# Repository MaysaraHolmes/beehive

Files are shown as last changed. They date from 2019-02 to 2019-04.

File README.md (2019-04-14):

<p align="center">
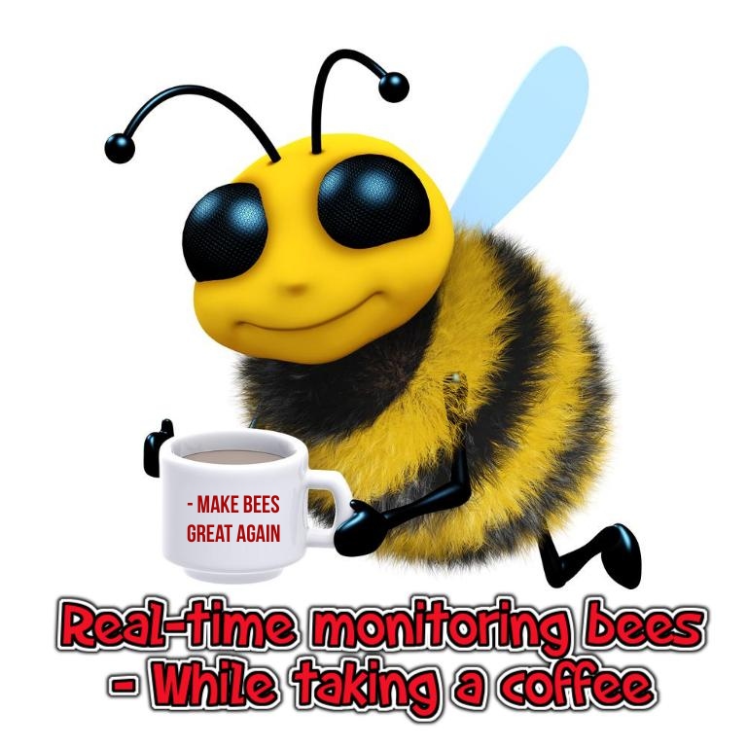
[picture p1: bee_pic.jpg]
FVCproductions Bee
</p>

# Real-Time Beehive Monitoring

We want to help beekeepers to keep an eye on their bees. By giving them insight on critical measurements we can monitor different events such as too low temperature, too high moisture, sufficient weight to harvest honey, as well as giving an estimate of how many bees went out of the beehive harvesting.

This project aims to set up a weather station with sensors and a fan to control the atmosphere inside the hive. The sensors output can be visualized through a website that can be hosted either locally on the Raspberry Pi, or hosted on the cloud (example [here](https://beehiveproject.herokuapp.com/)).

This project is done in partnership with the [Glasgow University Beekeeping Society](https://www.facebook.com/GUBeekeepingSociety/)

It was a success ! The Pi was able to make measurement of the ambiant temperature, pressure and humidity, as well as start the fan when the humidity got too high.

The website was displaying the value every 2 seconds while the fan was starting in as soon as the sensors triggered the alarm through a processor interrupt. Note, however, that the sensor provide data at more than 50Hz but it was decided the cap it to 2 second to avoid high traffic on the server (if hosted on the cloud).

## Table of contents
* [Setup](#setup)
* [General info](#general-info)
* [Technologies](#technologies)
* [Authors](#authors)
* [Images](#images)
* [Social media](#social-media)
## Setup

Instructions for installation can be found on the [installation wiki](https://github.com/MaysaraHolmes/beehive/wiki/Installation).

## General info
The code is simplified divided into three. Client, server and Fan. <br />
* The client is inteerupt by a timer every x millisecond reading the sensor data and sending it via udp to the server. <br />
* The server publish the data to our [example webpage](https://beehiveproject.herokuapp.com/) and saves the data to a database.
Additionally the server will send an email to registrered email-addresses everytime the humidity inside the beehive is too high. <br />
The website can be hosted either on a locally run server on the Raspberry Pi or hosted on a cloud based server.<br />
* The Fan is run depending on only one input pin. This pin is connected to the alarm on the humidity sensor inside the fan and will toggle instantaneously if the humidity goes above 80% humidity and off if it goes under 75% humidity. If the alarm pin toggles, it triggers an thread which will start or stop the fan depending if the pin goes high or low respectively. <br />
By this architecture the fan will be triggered even if the main code or the i2c bus fails to read the sensors. Making the code responsive and reliable. On the other hand if the alarm pin is disconnected you will still get an email/display on the webpage that the humidity inside the beehive is too high.
<br />
<br />
This projects architecture diagram:

<p align="center">
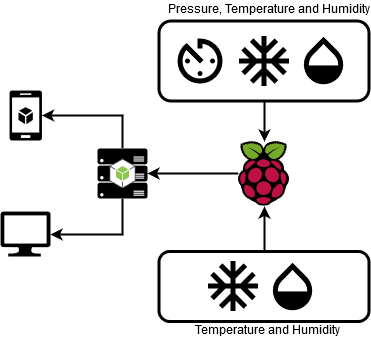
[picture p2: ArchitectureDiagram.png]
Architecture

</p>

Dependency graph for the C++ code:
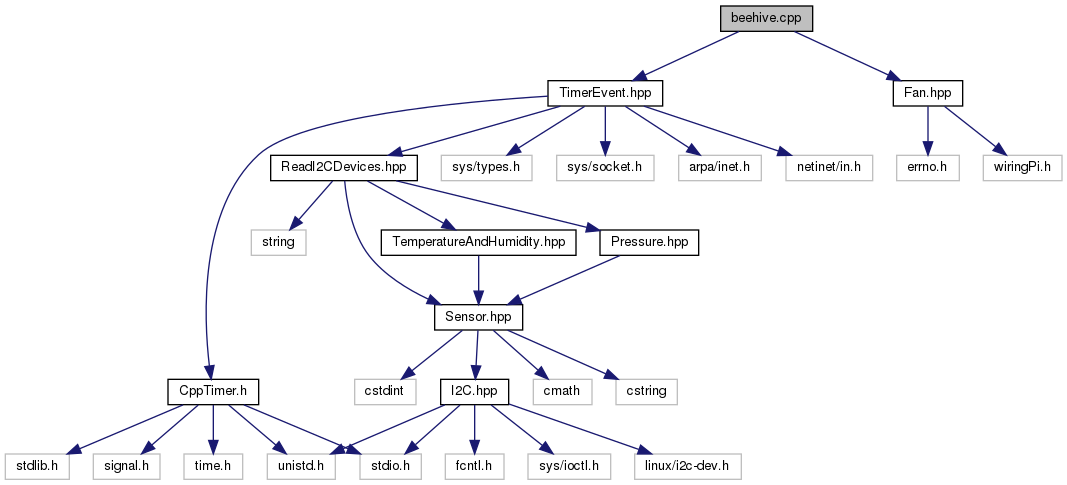
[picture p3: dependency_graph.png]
Dependency_graph

The doxygen generated c++ documentation can be found here: [beehive_code_documentation](https://github.com/MaysaraHolmes/beehive/blob/master/documentation/beehive_code_documentation.pdf)

## Technologies

Project is created with:
* Raspberry pi 3.0
* Sensors
	* ADC101C021 ADC
	* HIH6131 Temperatur & Humidity x2
	* MPL115A2 Barometer
	* P82B96 I2C Shifter
* Node Js/express Js server
* MySQL database.
* [WiringPi](http://wiringpi.com/reference/core-functions/) 
* [CppTimer.h](https://github.com/berndporr/cppTimer) 

## Authors

* **Remy Chatel, 2411062**  - [Github](https://github.com/RemyChatel) (Main responsibility: Hardware)

* **Maysara Alhindi, 2417665**  - [Github](https://github.com/MaysaraHolmes) (Main responsibility: Nodejs Server side and Front-end)

* **Trine Ødegård Olsen, 2420036**  - [Github](https://github.com/trineoo) (Main responsibility: C++ code)

## Images

The beehives in the backyard in the university of Glasgow
<p align="center">
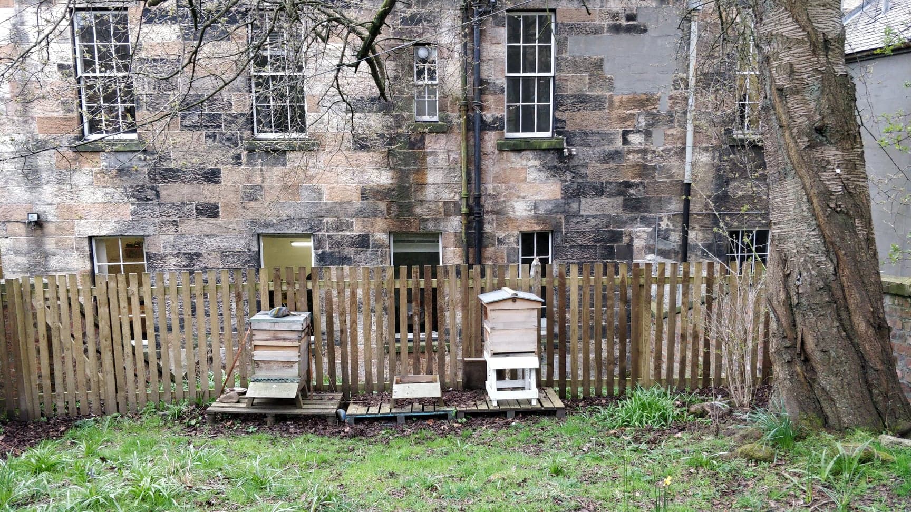
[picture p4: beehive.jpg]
beehive hive
	</p>
	 
Picture of the hardware, without the fan, soldered
<p align="center">
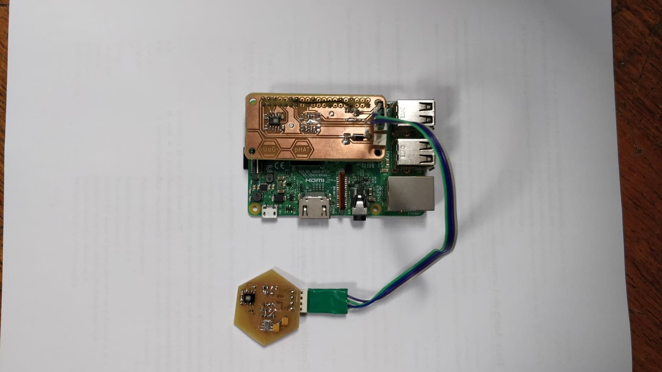
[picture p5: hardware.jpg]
hardware hw
	</p>

## Social media
* [Hackster](https://www.hackster.io/maysara-alhindi/real-time-beehive-monitoring-glasgow-university-5a986c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)
* [Hackaday](https://hackaday.io/project/164984-real-time-beehive-monitoring-glasgow-university)
* [Glasgow University Beekeeping Society](https://www.facebook.com/GUBeekeepingSociety/)

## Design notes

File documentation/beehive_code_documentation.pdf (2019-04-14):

## Beehive Project

### Generated by Doxygen 1.8.13

# Contents

1 Main Page | 1
2 Hierarchical Index | 3
3 Class Index | 5
4 File Index | 7
5 Class Documentation | 9

ii | CONTENTS

Generated by Doxygen

CONTENTS | iii

iv | CONTENTS
6 File Documentation | 37
Index | 39

## Chapter 1

# Main Page

Real-Time Beehive Monitoring

We want to help beekeepers to keep an eye on their bees. By giving them insight on critical measurements we can monitor different events such as too low temperature, too high moisture, sufficient weight to harvest honey, as well as giving an estimate of how many bees went out of the beehive harvesting.

Monitoring your beehive and get real-time measurements on the website (https://beehiveproject.herokuapp.com/)

This project is done in partnership with the Glasgow University Beekeeping Society (https://www.facebook.com/GUBeekeepingSociety/)

Table of contents

- Setup
- General info
- Technologies
- Authors

Setup

Instructions for installation can be found on the installation wiki. (https://github.com/MaysaraHolmes/beehive/wiki/Installation)

General info

This projects architecture diagram:

Dependency graph for the C++ code:

### 2 Main Page

Technologies

Project is created with:

- Raspberry pi 3.0
- Sensors

– ADC101C021 ADC
– HIH6131 Temperatur & Humidity x2 – MPL115A2 Barometer
– P82B96 I2C Shifter
- Node Js/express Js server
- MySQl database.

Authors

- Remy Chatel, 2411062 - Github (https://github.com/RemyChatel)
- Maysara Alhindi, 2417665 - Github (https://github.com/MaysaraHolmes)
- Trine Ødegård Olsen, 2420036 - Github (https://github.com/trineoo)

## Chapter 2

# Hierarchical Index

### 2.1 Class Hierarchy

This inheritance list is sorted roughly, but not completely, alphabetically:

CppTimer | 9
TimerEvent | 32
Fan | | 10
I2C | | 14
ReadI2CDevices | | 21
Sensor | | 25
Pressure | 16
TemperatureAndHumidity | 28

### 4 Hierarchical Index

## Chapter 3

# Class Index

### 3.1 Class List

Here are the classes, structs, unions and interfaces with brief descriptions:

Fan

I2C

Pressure

Sensor

TemperatureAndHumidity

### 6 Class Index

## Chapter 4

# File Index

### 4.1 File List

Here is a list of all documented files with brief descriptions:

CppTimer.h | ??
Fan.hpp | ??
I2C.hpp | ??
Pressure.hpp | | ??
ReadI2CDevices.hpp | | ??
Sensor.hpp | ??
TemperatureAndHumidity.hpp | ??
TimerEvent.hpp | ??

### 8 File Index

## Chapter 5

# Class Documentation

### 5.1 CppTimer Class Reference

Inheritance diagram for CppTimer:

CppTimer

TimerEvent

Public Member Functions

- void start (long nanosecs)
- virtual void timerEvent ()=0

Static Private Member Functions

- static void handler (int sig, siginfo_t ∗si, void ∗uc)

Private Attributes

- timer_t timerid
- struct sigevent sev
- struct sigaction sa
- struct itimerspec its

The documentation for this class was generated from the following file:

- CppTimer.h

### 10 Class Documentation

### 5.2 Fan Class Reference

A class to control Fan.

#include <Fan.hpp>

Collaboration diagram for Fan:

Fan saved_Fan_pointer

Public Member Functions

- Fan (int gpio=18, int interruptPin=22)

A constructor.
- void setPwm (int pwm_value)

Set the PWM value to the fan.
- void start ()

Start the Fan.
- void stop ()

Stop the Fan.
- ∼Fan ()

A destructor.

Static Public Member Functions

- static void onInterrupt ()

Static function triggers when the pin toggles.

Private Member Functions

- void setFanPointer ()

Set the static Fan pointer saved_Fan_pointer.

Private Attributes

- int gpio

A private variable.
- int interruptPin

A private variable.

5.2 Fan Class Reference | 11

Static Private Attributes

- static Fan ∗ saved_Fan_pointer = NULL

A private static variable.

### 5.2.1 Detailed Description

A class to control Fan.

Set different values for the Fan. Using a trigger pin connected to the humidity sensor inside the beehive, if the pin toggles (have threshold inside the sensor) it will trigger the onInterrupt() in this class and start or stop the Fan depending on if the pin goes to high or low.

### 5.2.2 Constructor & Destructor Documentation

### 5.2.2.1 Fan()

Fan::Fan (

int gpio = 18,

int interruptPin = 22 )

A constructor.

Set the private variables, default values is implemented

Parameters
gpio | an integer giving the gpio pin the fan is connected.
interruptPin | an integer giving the gpio pin the alarmpin is connected.

5.2.2.2 ∼Fan()

Fan::∼Fan ( )

A destructor.

Stops the Fan

### 5.2.3 Member Function Documentation

### 12 Class Documentation

### 5.2.3.1 onInterrupt()

void Fan::onInterrupt ( ) [static]

Static function triggers when the pin toggles.

Static to be called in real-time If the pin goes from high to low the stop() function is called If the pin goes from low to high the start() function is called

See also
start() and stop()

### 5.2.3.2 setFanPointer()

void Fan::setFanPointer ( ) [private]

Set the static Fan pointer saved_Fan_pointer.

Called by the constructor. Saves the objects in the corresponding private variables.

See also
Fan(int gpio = 18, int interruptPin=22), saved_Fan_pointer()

### 5.2.3.3 setPwm()

void Fan::setPwm (

int pwm_value )

Set the PWM value to the fan.

The PWM range is 0-1023.

### 5.2.3.4 start()

void Fan::start ( )

Start the Fan.

Calls the setPWM(1023) to maximise the Fan

See also
setPwm(int pwm_value)

5.2 Fan Class Reference | 13

### 5.2.3.5 stop()

void Fan::stop ( )

Stop the Fan.

Calls the setPWM(0) to stop the Fan

See also
setPwm(int pwm_value)

### 5.2.4 Member Data Documentation

### 5.2.4.1 gpio

int Fan::gpio [private]

A private variable.

Integer to hold the gpio pin the Fan is connected.

### 5.2.4.2 interruptPin

int Fan::interruptPin [private]

A private variable.

Integer to hold the gpio pin the alarmpin form humidity sensor is connected.

### 5.2.4.3 saved_Fan_pointer

Fan ∗ Fan::saved_Fan_pointer = NULL [static], [private]

A private static variable.

Assuming we only have one fan to trigger. Need a static pointer to the object so that the static interrupt function know which fan to set. If we have multiple fans on different pins, this has to be changed to a list/vector/pointer.

The documentation for this class was generated from the following files:

- Fan.hpp
- Fan.cpp

### 14 Class Documentation

### 5.3 I2C Class Reference

A I2C class handling the I2C bus.

#include <I2C.hpp>

Public Member Functions

- I2C (char ∗portI2C, int slaveAddr)

A constructor.
- void readI2C (int bytesToRead, unsigned char ∗global_buffer)

Read data from the peripheral .
- int writeI2C (int length, unsigned char ∗buffer)
- int writeI2C (int length)

Write data to the peripheral .

Private Attributes

- int file_i2c

A private variable.
- unsigned char buffer [5] = {0}

A private variable.

### 5.3.1 Detailed Description

A I2C class handling the I2C bus.

Handling I2C bus intended to allow multiple "slave" digital chips to communicate with the master i.e Raspberry PI. Every sensor connected to the bus has their own I2C-object.

### 5.3.2 Constructor & Destructor Documentation

### 5.3.2.1 I2C()

I2C::I2C (

char ∗ portI2C,

int slaveAddr )

A constructor.

Open the I2C bus and tell the kernel the I2C address of the slave.

Parameters
portI2C | a char pointer holding the which I2C bus on the Raspberry the peripheral is connected to.
slaveAddr | an integer holding the address to the peripheral.

5.3 I2C Class Reference | 15

### 5.3.3 Member Function Documentation

### 5.3.3.1 readI2C()

void I2C::readI2C (

int bytesToRead,

unsigned char ∗ global_buffer )

Read data from the peripheral .

Parameters
bytesToRead | an integer giving numbers of bytes to read.
global_buffer | an unsigned char pointer where the data read is saved.

### 5.3.3.2 writeI2C() [1/2]

int I2C::writeI2C (

int length,

unsigned char ∗ buffer )

Parameters
length | an integer giving numbers of bytes to write.
buffer | an unsigned char pointer pointing to the data to write.

### 5.3.3.3 writeI2C() [2/2]

int I2C::writeI2C (

int length )

Write data to the peripheral .

Using the private buffer in the object to write default value

Parameters
length an integer giving numbers of bytes to write.

### 16 Class Documentation

### 5.3.4 Member Data Documentation

### 5.3.4.1 buffer

unsigned char I2C::buffer[5] = {0} [private]

A private variable.

Used if you want to write to a peripheral, starting a conversation

### 5.3.4.2 file_i2c

int I2C::file_i2c [private]

A private variable.

To communicate with the I2C bus

The documentation for this class was generated from the following files:

- I2C.hpp
- I2C.cpp

### 5.4 Pressure Class Reference

A class for the MPL115A2 Barometer sensor.

#include <Pressure.hpp>

Inheritance diagram for Pressure:

Pressure

Sensor

5.4 Pressure Class Reference | 17

Collaboration diagram for Pressure:

Pressure

Sensor

I2C

bus

Public Member Functions
- Pressure (char ∗portI2C, int addrI2C, unsigned char ∗global_buffer)

A constructor.
- void readCoefficients (unsigned char ∗global_buffer)

Call the I2C-object write and read function to get sensor coefficients.
- void readI2C (unsigned char ∗global_buffer)

Call the I2C-object read function.
- int writeI2C ()

Call the I2C-object write function.
- float getPressure ()

Convert the humidity bits into kPa.
- float getTemp ()

Convert the temperature bits into degrees.
- ∼Pressure ()

A destructor.

Private Attributes
- float a0

A private variable.
- float b1

A private variable.
- float b2

A private variable.
- float c12

A private variable.
- int pressure

A private variable.
- int temp

A private variable.
- float pressureComp

A private variable.

### 18 Class Documentation

Additional Inherited Members

### 5.4.1 Detailed Description

A class for the MPL115A2 Barometer sensor.

Handling communication with the sensor, and converting the sensor measurements to human readable values

### 5.4.2 Constructor & Destructor Documentation

### 5.4.2.1 Pressure()

Pressure::Pressure (

char ∗ portI2C,

int addrI2C,

unsigned char ∗ global_buffer )

A constructor.

Call the Sensor constructor and readCoefficients(unsigned char∗ global_buffer)

Parameters
portI2C | a char pointer holding the which I2C bus on the Raspberry the peripheral is connected to.
addrI2C | an integer holding the address to the peripheral.

See also
Sensor(int bytesToRead, int bytesToWrite, char∗ portI2C, int addrI2C)

5.4.2.2 ∼Pressure()

Pressure::∼Pressure ( )

A destructor.

Empty, can be used if more functions are integrated

### 5.4.3 Member Function Documentation

5.4 Pressure Class Reference | 19

### 5.4.3.1 getPressure()

float Pressure::getPressure ( )

Convert the humidity bits into kPa.

Returns
The humidity in kPa.

### 5.4.3.2 getTemp()

float Pressure::getTemp ( )

Convert the temperature bits into degrees.

Returns
The temperature in degrees.

### 5.4.3.3 readCoefficients()

void Pressure::readCoefficients (

unsigned char ∗ global_buffer )

Call the I2C-object write and read function to get sensor coefficients.

Write (uint8_t)(0x04) to the sensor, followed by a read to get the coefficients we need to decrypt the values from the pressure sensor. Saves the coefficients in the corresponding private variables.

Parameters
global_buffer an unsigned char pointer where the data read is saved.

### 5.4.3.4 readI2C()

void Pressure::readI2C (

unsigned char ∗ global_buffer ) [virtual]
Call the I2C-object read function.

Get the data read form the sensor and split the data into pressure, temperature and calculate the pressure compo-nent bits and saves them to the corresponding private variable.

### 20 Class Documentation

Parameters
global_buffer an unsigned char pointer where the data read is saved.

Implements Sensor.

### 5.4.4 Member Data Documentation

### 5.4.4.1 a0

float Pressure::a0 [private]
A private variable.

variable to hold the floating point coefficient a0 needed to convert the read sensor bit to a human readable value

### 5.4.4.2 b1

float Pressure::b1 [private]
A private variable.

variable to hold the floating point coefficient b1 needed to convert the read sensor bit to a human readable value

### 5.4.4.3 b2

float Pressure::b2 [private]
A private variable.

variable to hold the floating point coefficient b2 needed to convert the read sensor bit to a human readable value

### 5.4.4.4 c12

float Pressure::c12 [private]
A private variable.

variable to hold the floating point coefficient c2 needed to convert the read sensor bit to a human readable value

### 5.4.4.5 pressure

int Pressure::pressure [private]
A private variable.

Holding the newest pressure-bit reading from the sensor

5.5 ReadI2CDevices Class Reference | 21

### 5.4.4.6 pressureComp

float Pressure::pressureComp [private]

A private variable.

Intermediate variable needed to convert the sensor data to a human readable value. Calculated by combining all the private variables

### 5.4.4.7 temp

int Pressure::temp [private]

A private variable.

Holding the newest temperature-bit reading from the sensor

The documentation for this class was generated from the following files:

- Pressure.hpp
- Pressure.cpp

### 5.5 ReadI2CDevices Class Reference

Collaboration diagram for ReadI2CDevices:

ReadI2CDevices

Sensor

pr
th1
th2

I2C

bus

### 22 Class Documentation

Public Member Functions

- ReadI2CDevices ()

A constructor.
- void writeAll ()

Write to all the peripherals.
- std::string readAll ()

Read data from all the peripherals.
- ∼ReadI2CDevices ()

A destructor.

Private Member Functions

- void createSensorObjects ()

Create all the sensor objects we want to communicate with.

Private Attributes

- unsigned char global_buffer [20] ={0}

A private variable.
- Sensor ∗ th1

A private variable.
- Sensor ∗ th2

A private variable.
- Sensor ∗ pr

A private variable.

### 5.5.1 Constructor & Destructor Documentation

### 5.5.1.1 ReadI2CDevices()

ReadI2CDevices::ReadI2CDevices ( )

A constructor.

Call the function createSensorObjects();

See also
createSensorObjects()

5.5 ReadI2CDevices Class Reference | 23

5.5.1.2 ∼ReadI2CDevices()

ReadI2CDevices::∼ReadI2CDevices ( )

A destructor.

Deallocates memory from heap

### 5.5.2 Member Function Documentation

### 5.5.2.1 createSensorObjects()

void ReadI2CDevices::createSensorObjects ( ) [private]

Create all the sensor objects we want to communicate with.

Called by the constructor. Saves the objects in the corresponding private variables.

See also
ReadI2CDevices();

### 5.5.2.2 readAll()

std::string ReadI2CDevices::readAll ( )

Read data from all the peripherals.

Call the pure virtual function readI2C(unsigned char∗ global_buffer) in Sensor.hpp for all the sensors. Sends the private global_buffer to save the readings.

Returns
A string of all the human readable data read form the sensors

See also
readI2C(unsigned char∗ global_buffer) = 0;

### 24 Class Documentation

### 5.5.2.3 writeAll()

void ReadI2CDevices::writeAll ( )
Write to all the peripherals.

Call the virtual function writeI2C() in Sensor.hpp for all the sensors

See also
writeI2C()

### 5.5.3 Member Data Documentation

### 5.5.3.1 global_buffer

unsigned char ReadI2CDevices::global_buffer[20] ={0} [private]
A private variable.

Global buffer where all the sensors saves the measurements.

### 5.5.3.2 pr

Sensor∗ ReadI2CDevices::pr [private]

A private variable.

Sensor object, pointing to the pressure sensor on I2C bus 1.

### 5.5.3.3 th1

Sensor∗ ReadI2CDevices::th1 [private]

A private variable.

Sensor object, pointing to the temperature and humidity sensor on I2C bus 1.

### 5.5.3.4 th2

Sensor∗ ReadI2CDevices::th2 [private]

A private variable.

Sensor object, pointing to the temperature and humidity sensor on I2C bus 2.

The documentation for this class was generated from the following files:

- ReadI2CDevices.hpp
- ReadI2CDevices.cpp

5.6 Sensor Class Reference | 25

### 5.6 Sensor Class Reference

An abstract class.

#include <Sensor.hpp>

Inheritance diagram for Sensor:

Sensor

Pressure TemperatureAndHumidity

Collaboration diagram for Sensor:

Sensor

I2C

bus

Public Member Functions

- Sensor (int bytesToRead, int bytesToWrite, char ∗portI2C, int addrI2C)

A constructor.
- virtual void readI2C (unsigned char ∗global_buffer)=0

A pure virtual member.
- virtual int writeI2C ()

A virtual member.
- ∼Sensor ()

A destructor.

### 26 Class Documentation

Protected Attributes

- int bytesToRead

A private variable.
- int bytesToWrite

A private variable.
- I2C ∗ bus

A private variable.

### 5.6.1 Detailed Description

An abstract class.

Used as a base class for sensors connected to the I2C bus of the RaspberryPi

### 5.6.2 Constructor & Destructor Documentation

### 5.6.2.1 Sensor()

Sensor::Sensor (

int bytesToRead,

int bytesToWrite,

char ∗ portI2C,

int addrI2C ) [inline]

A constructor.

Create a new I2C object used to communicate with the sensor.

Parameters
bytesToRead | default bytes to read form the I2C bus
bytesToWrite | default bytes to write form the I2C bus
portI2C | a char pointer holding which I2C bus on the Raspberry the peripheral is connected to.
addrI2C | an integer holding the address to the peripheral.

See also
I2C(char∗ portI2C, int slaveAddr)

5.6.2.2 ∼Sensor()

Sensor::∼Sensor ( ) [inline]
A destructor.
Deallocates memory from heap

5.6 Sensor Class Reference | 27

### 5.6.3 Member Function Documentation

### 5.6.3.1 readI2C()

virtual void Sensor::readI2C (

unsigned char ∗ global_buffer ) [pure virtual]

A pure virtual member.

Read data from the peripheral .

Parameters
global_buffer an unsigned char pointer where the data read is saved.

Implemented in Pressure, and TemperatureAndHumidity.

### 5.6.3.2 writeI2C()

virtual int Sensor::writeI2C ( ) [inline], [virtual]
A virtual member.

Write data to the peripheral .

Reimplemented in Pressure, and TemperatureAndHumidity.

### 5.6.4 Member Data Documentation

### 5.6.4.1 bus

I2C∗ Sensor::bus [protected]

A private variable.

Holding the sensor I2C bus object created in the constructor

### 5.6.4.2 bytesToRead

int Sensor::bytesToRead [protected]
A private variable.

Holding the sensor default bytes to read form the I2C bus

### 28 Class Documentation

### 5.6.4.3 bytesToWrite

int Sensor::bytesToWrite [protected]
A private variable.

Holding the sensor default bytes to write form the I2C bus

The documentation for this class was generated from the following file:

- Sensor.hpp

### 5.7 TemperatureAndHumidity Class Reference

A class for the HIH6131 Temperatur & Humidity sensor.

#include <TemperatureAndHumidity.hpp>

Inheritance diagram for TemperatureAndHumidity:

TemperatureAndHumidity

Sensor

Collaboration diagram for TemperatureAndHumidity:

TemperatureAndHumidity

Sensor

I2C

bus

5.7 TemperatureAndHumidity Class Reference | 29

Public Member Functions

- TemperatureAndHumidity (char ∗portI2C, int addrI2C)

A constructor.
- void readI2C (unsigned char ∗global_buffer)

Call the I2C-object read function.
- int writeI2C ()

Call the I2C-object write function.
- unsigned int getStatus ()

Convert the status bits into a integer from 0-3.
- double getTemp ()

Convert the temperature bits into degrees.
- double getHum ()

Convert the humidity bits into RH.
- ∼TemperatureAndHumidity ()

A destructor.

Private Attributes

- uint8_t status

A private variable.
- uint16_t humidity

A private variable.
- uint16_t temperature

A private variable.

Additional Inherited Members

### 5.7.1 Detailed Description

A class for the HIH6131 Temperatur & Humidity sensor.

Handling how to communicate with the sensor, and converting the sensor measurements to human readable values

### 5.7.2 Constructor & Destructor Documentation

### 5.7.2.1 TemperatureAndHumidity()

TemperatureAndHumidity::TemperatureAndHumidity (

char ∗ portI2C,

int addrI2C )

A constructor.

Call the Sensor constructor

### 30 Class Documentation

Parameters
portI2C | a char pointer holding the which I2C bus on the Raspberry the peripheral is connected to.
addrI2C | an integer holding the address to the peripheral.

See also
Sensor(int bytesToRead, int bytesToWrite, char∗ portI2C, int addrI2C)

5.7.2.2 ∼TemperatureAndHumidity()

TemperatureAndHumidity::∼TemperatureAndHumidity ( )

A destructor.

Empty, can be used if more functions are integrated

### 5.7.3 Member Function Documentation

### 5.7.3.1 getHum()

double TemperatureAndHumidity::getHum ( )

Convert the humidity bits into RH.

Returns
The humidity in RH.

### 5.7.3.2 getStatus()

unsigned int TemperatureAndHumidity::getStatus ( )

Convert the status bits into a integer from 0-3.

Returns
The status of the sensor.

5.7 TemperatureAndHumidity Class Reference | 31

### 5.7.3.3 getTemp()

double TemperatureAndHumidity::getTemp ( )

Convert the temperature bits into degrees.

Returns
The temperature in degrees.

### 5.7.3.4 readI2C()

void TemperatureAndHumidity::readI2C (

unsigned char ∗ global_buffer ) [virtual]

Call the I2C-object read function.

Get the data read form the sensor and split the data into status, humidity and temperatur bits and saves them to the corresponding private variable.

Parameters
global_buffer an unsigned char pointer where the data read is saved.

Implements Sensor.

### 5.7.4 Member Data Documentation

### 5.7.4.1 humidity

uint16_t TemperatureAndHumidity::humidity [private]

A private variable.

Holding the newest humidity-bit reading from the sensor

### 5.7.4.2 status

uint8_t TemperatureAndHumidity::status [private]

A private variable.

Holding the newest status-bit reading from the sensor

### 32 Class Documentation

### 5.7.4.3 temperature

uint16_t TemperatureAndHumidity::temperature [private]

A private variable.

Holding the newest temperature-bit reading from the sensor

The documentation for this class was generated from the following files:

- TemperatureAndHumidity.hpp
- TemperatureAndHumidity.cpp

### 5.8 TimerEvent Class Reference

Inheritance diagram for TimerEvent:

TimerEvent

CppTimer

5.8 TimerEvent Class Reference | 33

Collaboration diagram for TimerEvent:

Public Member Functions

- TimerEvent ()

A constructor.
- ∼TimerEvent ()

A destructor.

Private Member Functions

- void timerEvent ()

A private member.

Private Attributes

- ReadI2CDevices ∗ r

A private variable.
- int sockfd

A private variable.
- struct sockaddr_in servaddr

A private variable.

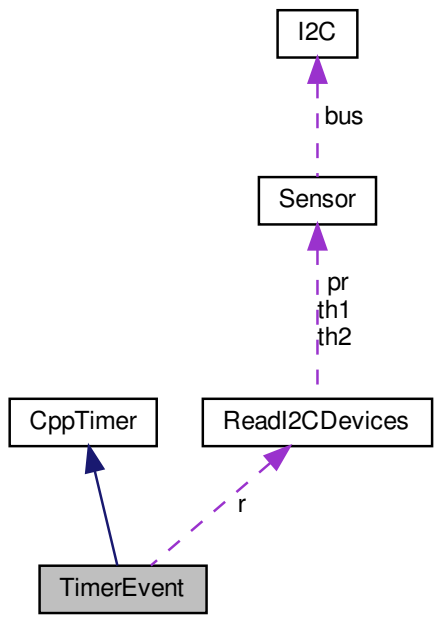
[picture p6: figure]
TimerEvent; CppTimer; ReadI2CDevices; Sensor; bus

### 34 Class Documentation

### 5.8.1 Constructor & Destructor Documentation

### 5.8.1.1 TimerEvent()

TimerEvent::TimerEvent ( )

A constructor.

Create a new ReadI2CDevices-object and saves it to the corresponding private variable. Setup and configure the socket

5.8.1.2 ∼TimerEvent()

TimerEvent::∼TimerEvent ( )

A destructor.

Deallocates memory from heap

### 5.8.2 Member Function Documentation

### 5.8.2.1 timerEvent()

void TimerEvent::timerEvent ( ) [private], [virtual]

A private member.

Called by the CppTimer.h Get a string of all the sensor data and send it to the server

Implements CppTimer.

### 5.8.3 Member Data Documentation

### 5.8.3.1 r

ReadI2CDevices∗ TimerEvent::r [private]

A private variable.

Object to get all the gathered sensor data.

5.8 TimerEvent Class Reference | 35

### 5.8.3.2 servaddr

struct sockaddr_in TimerEvent::servaddr [private]

A private variable.

Struct containing the server address, port number and host number

### 5.8.3.3 sockfd

int TimerEvent::sockfd [private]

A private variable.

The socket created in the constructor

The documentation for this class was generated from the following files:

- TimerEvent.hpp
- TimerEvent.cpp

### 36 Class Documentation

## Chapter 6

# File Documentation

### 6.1 beehive.cpp File Reference

#include "TimerEvent.hpp"

#include "Fan.hpp"

Include dependency graph for beehive.cpp:

beehive.cpp

TimerEvent.hpp | Fan.hpp

CppTimer.h

ReadI2CDevices.hpp | sys/types.h | sys/socket.h | arpa/inet.h | netinet/in.h
stdlib.h | signal.h | time.h | unistd.h | stdio.h

TemperatureAndHumidity.hpp

Sensor.hpp

string | Pressure.hpp
cstdint | I2C.hpp | cmath | cstring
fcntl.h | sys/ioctl.h | linux/i2c-dev.h
errno.h | wiringPi.h

Functions

- int main (int argc, const char ∗argv[ ])

### 6.1.1 Detailed Description

Project start

### 6.1.2 Function Documentation

### 38 File Documentation

### 6.1.2.1 main()

int main (

int argc,

const char ∗ argv[ ] )

Create a Fan object so the interrupt bin is set to the default value (using the default gpio pin in the Fan constructor) Create a TimerEvent object to start the timer which trigger the sensor-readings.

# Index

∼Fan
Fan, 11
∼Pressure
Pressure, 18
∼ReadI2CDevices
ReadI2CDevices, 22
∼Sensor
Sensor, 26
∼TemperatureAndHumidity
TemperatureAndHumidity, 30 ∼TimerEvent
TimerEvent, 34

a0
Pressure, 20

b1
Pressure, 20
b2
Pressure, 20
beehive.cpp, 37
main, 37
buffer
I2C, 16
bus
Sensor, 27
bytesToRead
Sensor, 27
bytesToWrite
Sensor, 27

c12
Pressure, 20
CppTimer, 9
createSensorObjects
ReadI2CDevices, 23

Fan, 10
∼Fan, 11
Fan, 11
gpio, 13
interruptPin, 13
onInterrupt, 11
saved_Fan_pointer, 13
setFanPointer, 12
setPwm, 12
start, 12
stop, 12
file_i2c
I2C, 16

getHum
TemperatureAndHumidity, 30 getPressure
Pressure, 18
getStatus
TemperatureAndHumidity, 30 getTemp
Pressure, 19
TemperatureAndHumidity, 30 global_buffer
ReadI2CDevices, 24
gpio
Fan, 13

humidity
TemperatureAndHumidity, 31

I2C, 14
buffer, 16
file_i2c, 16
I2C, 14
readI2C, 15
writeI2C, 15
interruptPin
Fan, 13

main
beehive.cpp, 37

onInterrupt
Fan, 11

pr
ReadI2CDevices, 24
Pressure, 16
∼Pressure, 18
a0, 20
b1, 20
b2, 20
c12, 20
getPressure, 18
getTemp, 19
Pressure, 18
pressure, 20
pressureComp, 20
readCoefficients, 19
readI2C, 19
temp, 21
pressure
Pressure, 20
pressureComp

### 40 INDEX

Pressure, 20

r
TimerEvent, 34
readAll
ReadI2CDevices, 23
readCoefficients
Pressure, 19
ReadI2CDevices, 21
∼ReadI2CDevices, 22
createSensorObjects, 23
global_buffer, 24
pr, 24
readAll, 23
ReadI2CDevices, 22
th1, 24
th2, 24
writeAll, 23
readI2C
I2C, 15
Pressure, 19
Sensor, 27
TemperatureAndHumidity, 31

saved_Fan_pointer
Fan, 13
Sensor, 25
∼Sensor, 26
bus, 27
bytesToRead, 27
bytesToWrite, 27
readI2C, 27
Sensor, 26
writeI2C, 27
servaddr
TimerEvent, 34
setFanPointer
Fan, 12
setPwm
Fan, 12
sockfd
TimerEvent, 35
start
Fan, 12
status
TemperatureAndHumidity, 31 stop
Fan, 12

temp
Pressure, 21
temperature
TemperatureAndHumidity, 31 TemperatureAndHumidity, 28 ∼TemperatureAndHumidity, 30 getHum, 30
getStatus, 30
getTemp, 30
humidity, 31

readI2C, 31
status, 31
temperature, 31
TemperatureAndHumidity, 29 th1
ReadI2CDevices, 24
th2
ReadI2CDevices, 24
TimerEvent, 32
∼TimerEvent, 34
r, 34
servaddr, 34
sockfd, 35
TimerEvent, 34
timerEvent, 34
timerEvent
TimerEvent, 34

writeAll
ReadI2CDevices, 23
writeI2C
I2C, 15
Sensor, 27

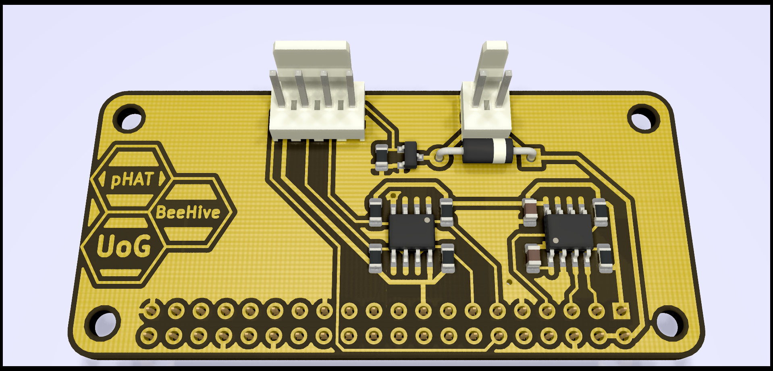
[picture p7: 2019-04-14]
documentation/pHAT_v3.3_barecopper.png

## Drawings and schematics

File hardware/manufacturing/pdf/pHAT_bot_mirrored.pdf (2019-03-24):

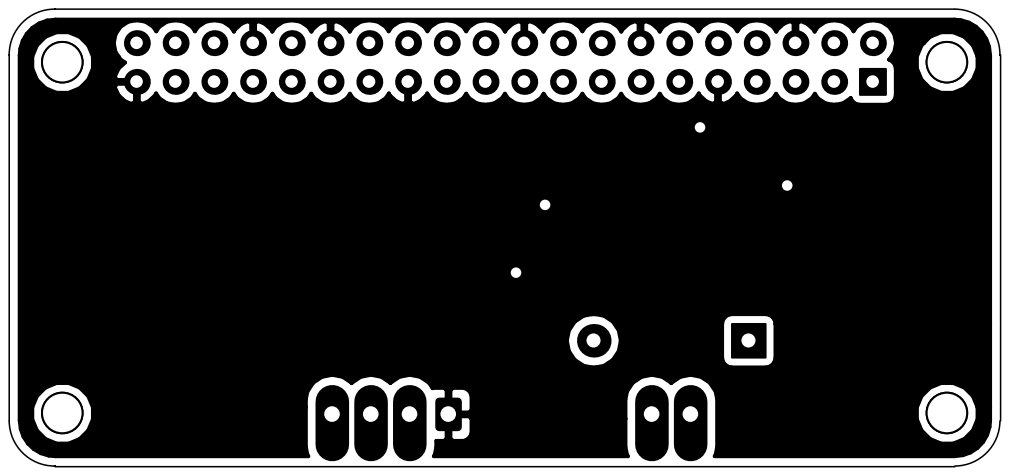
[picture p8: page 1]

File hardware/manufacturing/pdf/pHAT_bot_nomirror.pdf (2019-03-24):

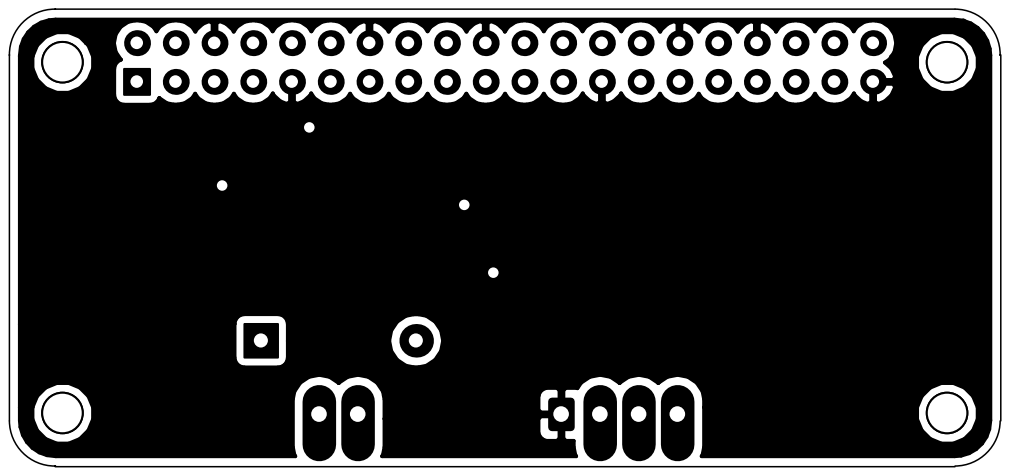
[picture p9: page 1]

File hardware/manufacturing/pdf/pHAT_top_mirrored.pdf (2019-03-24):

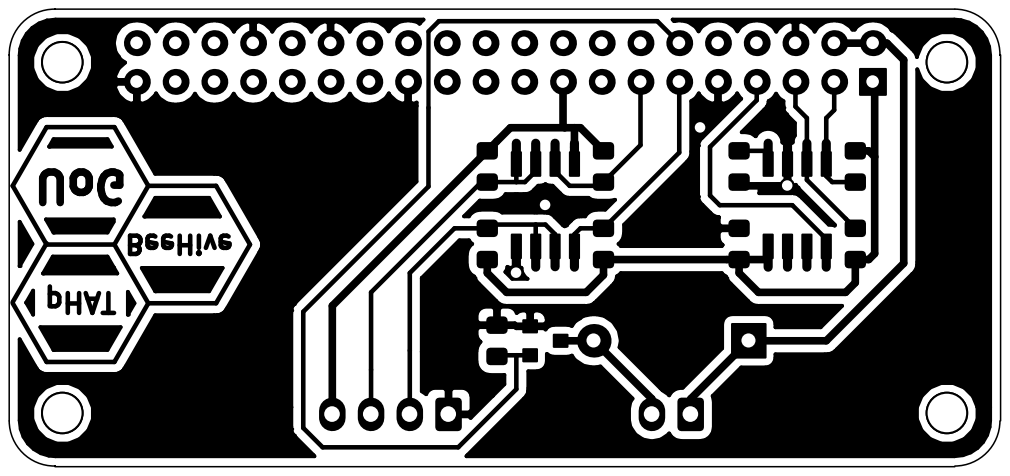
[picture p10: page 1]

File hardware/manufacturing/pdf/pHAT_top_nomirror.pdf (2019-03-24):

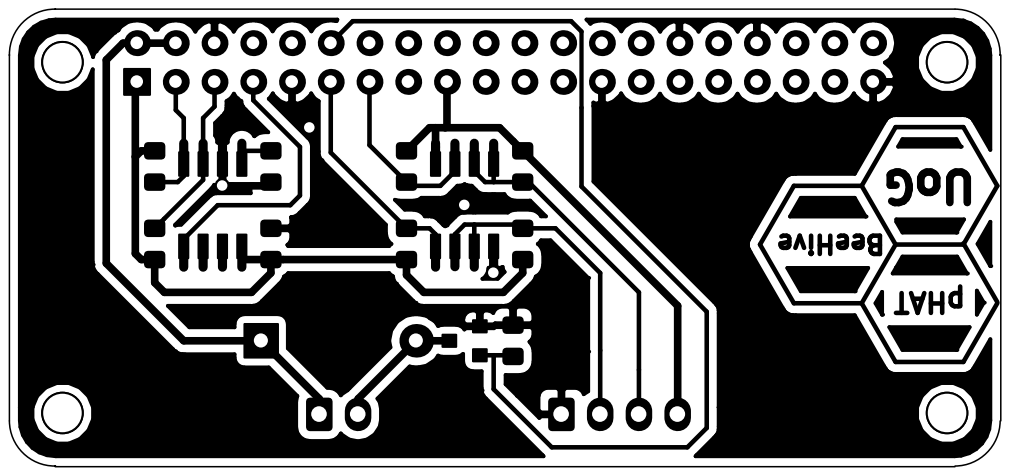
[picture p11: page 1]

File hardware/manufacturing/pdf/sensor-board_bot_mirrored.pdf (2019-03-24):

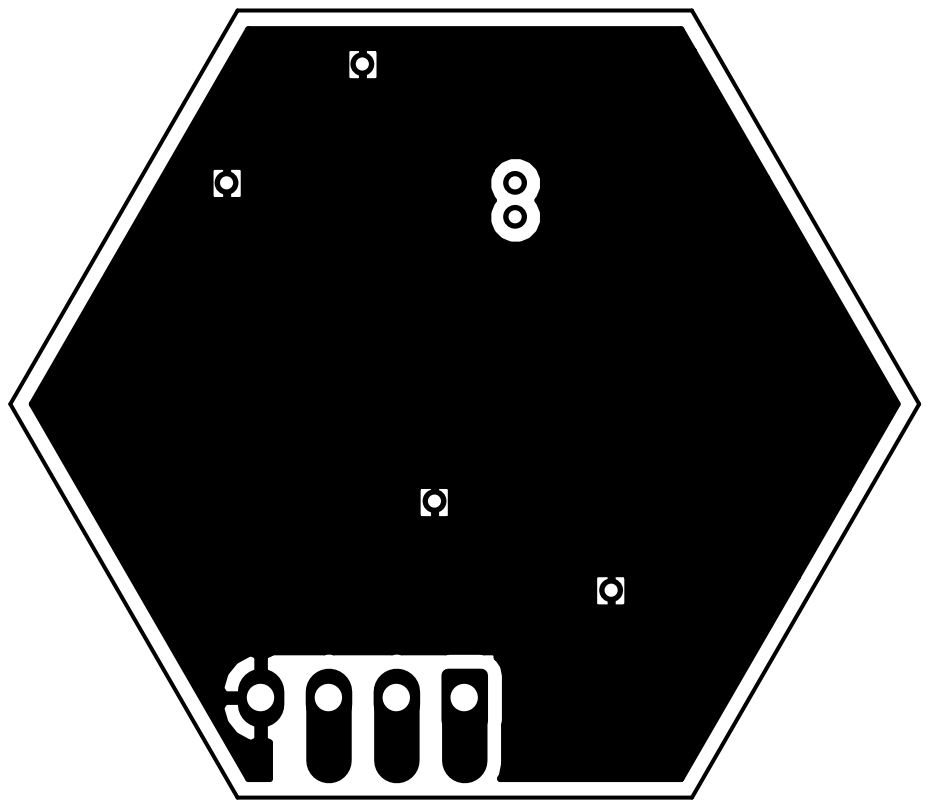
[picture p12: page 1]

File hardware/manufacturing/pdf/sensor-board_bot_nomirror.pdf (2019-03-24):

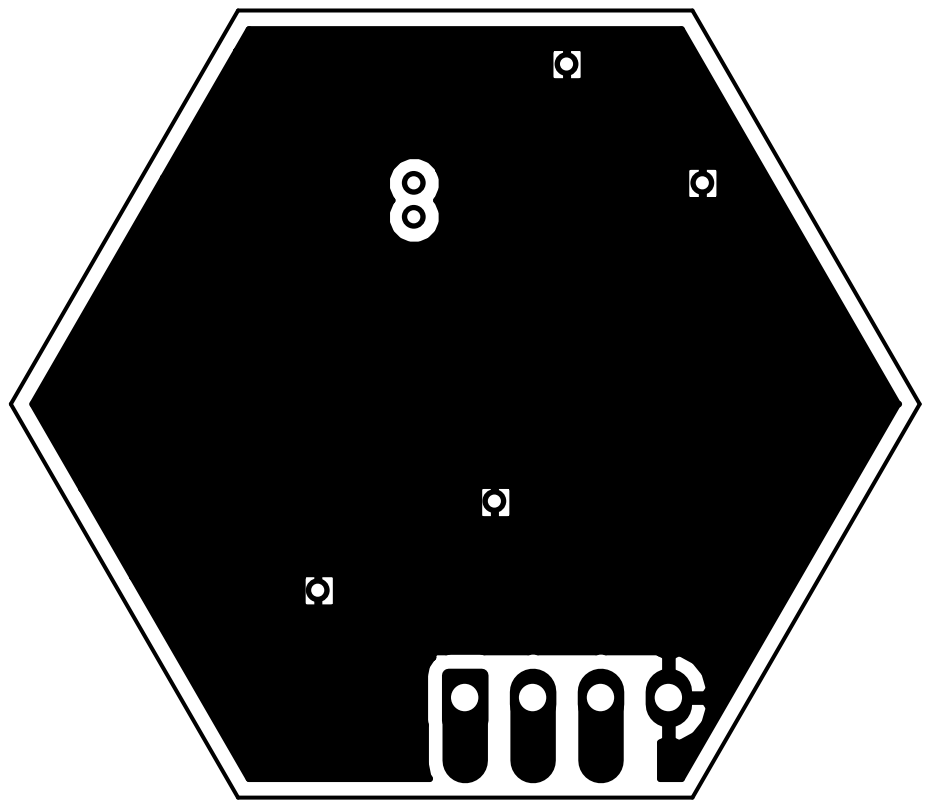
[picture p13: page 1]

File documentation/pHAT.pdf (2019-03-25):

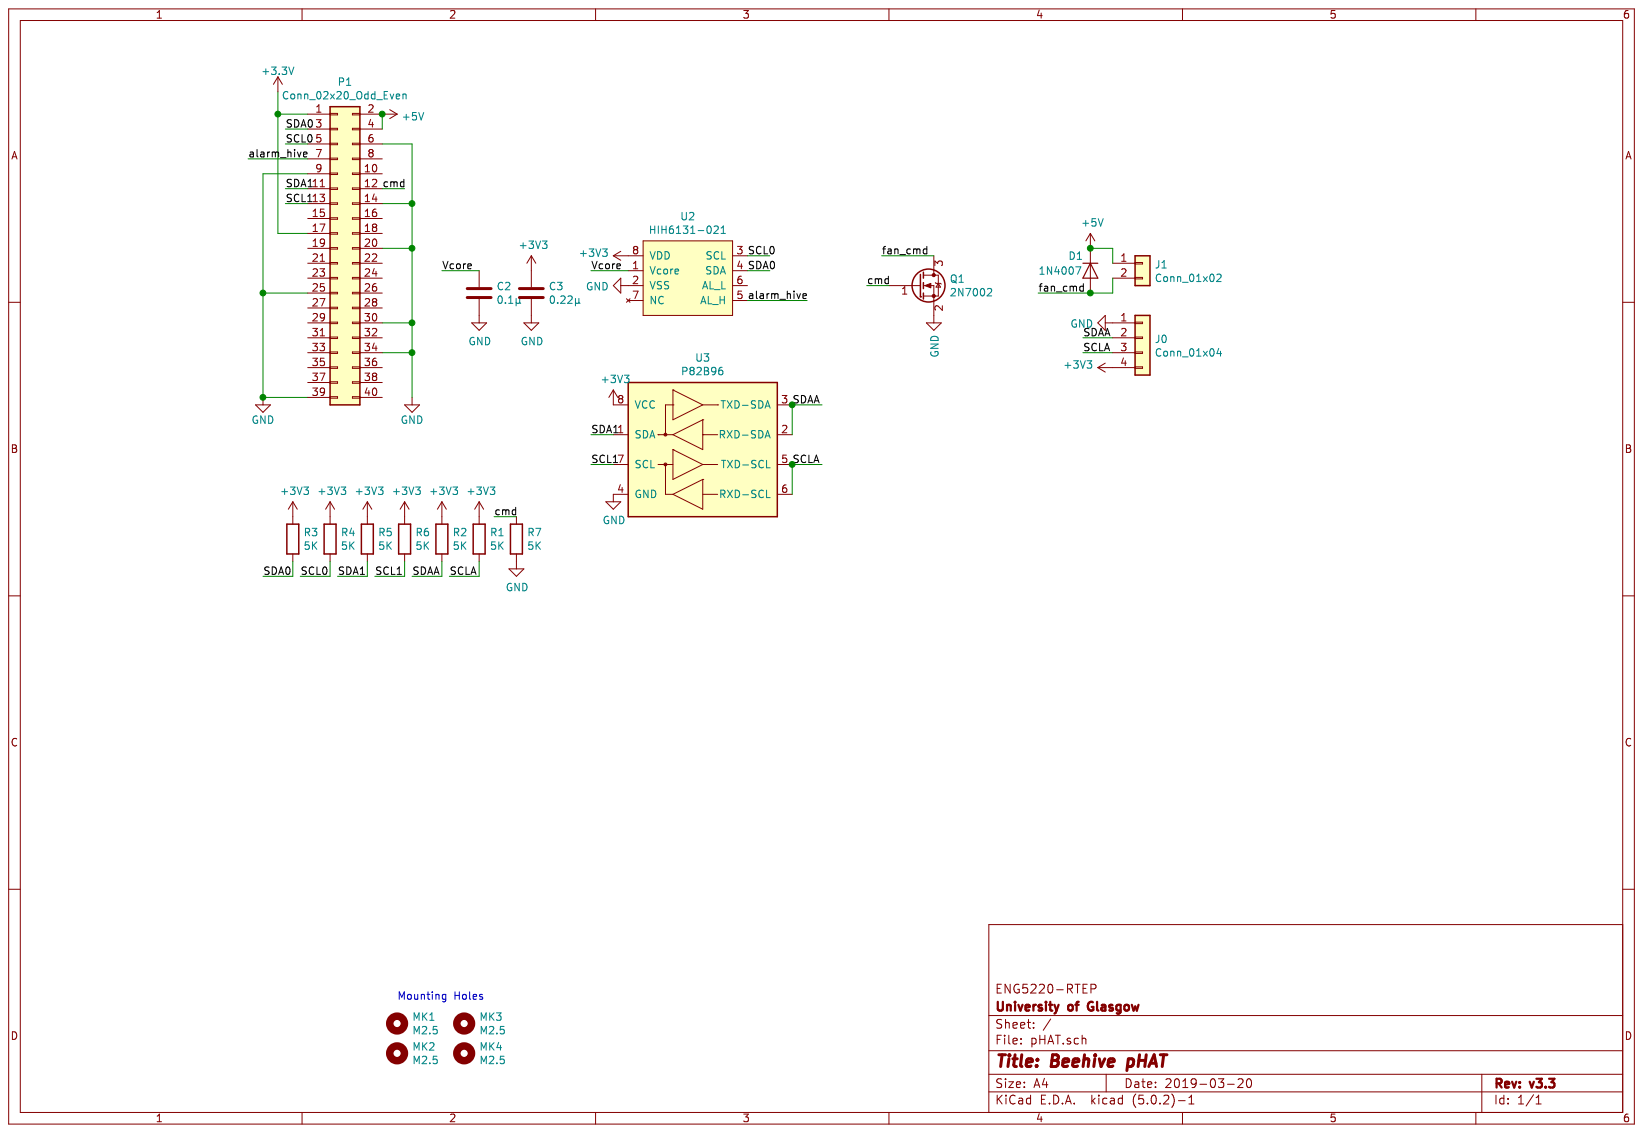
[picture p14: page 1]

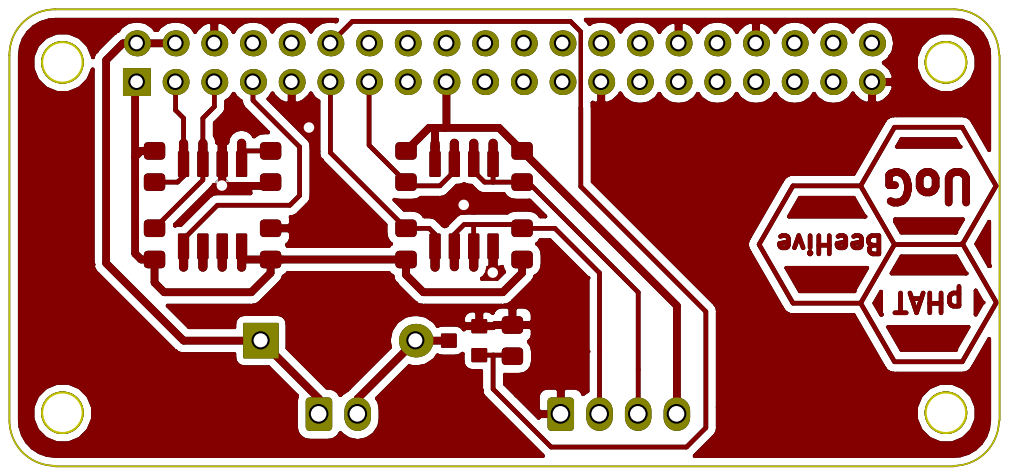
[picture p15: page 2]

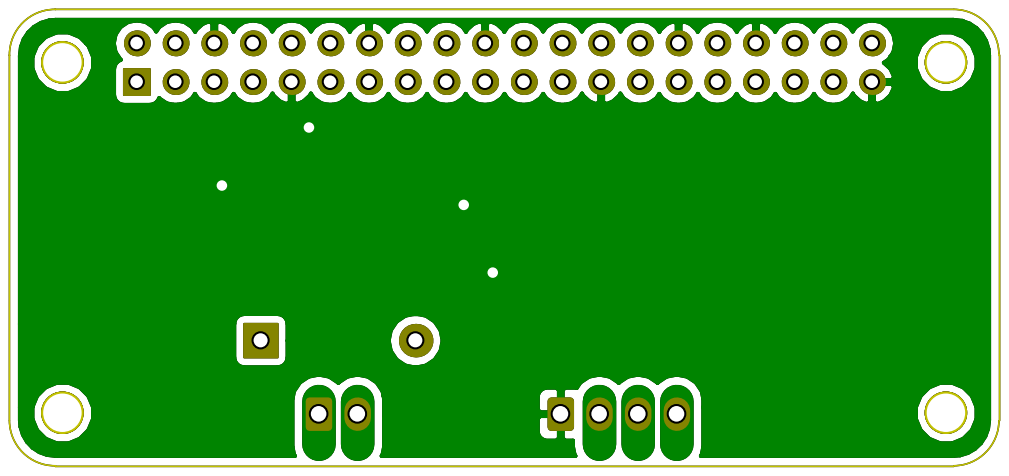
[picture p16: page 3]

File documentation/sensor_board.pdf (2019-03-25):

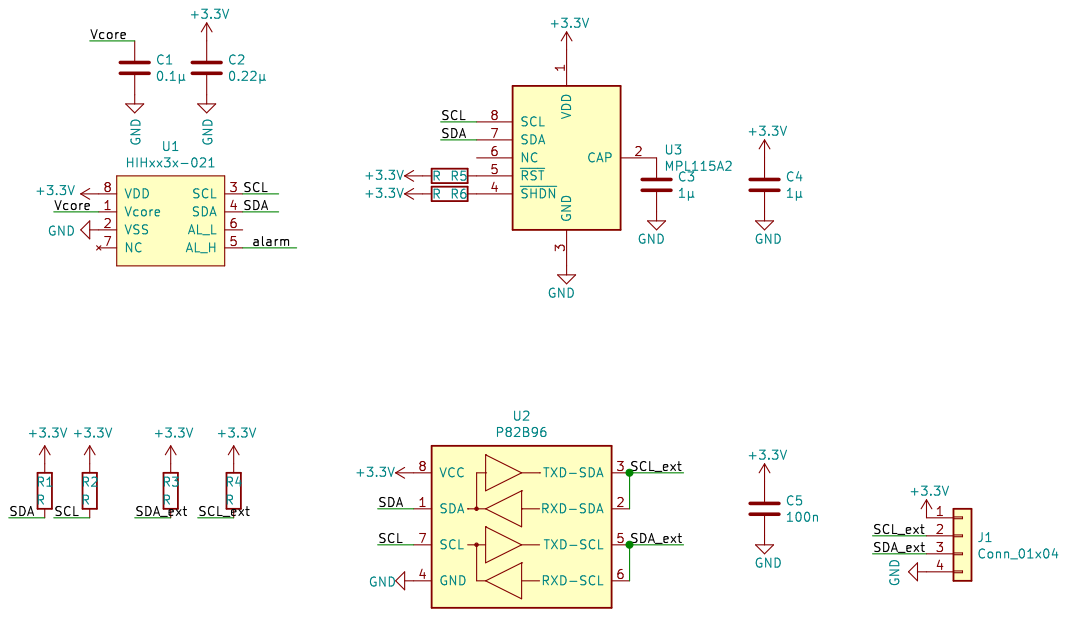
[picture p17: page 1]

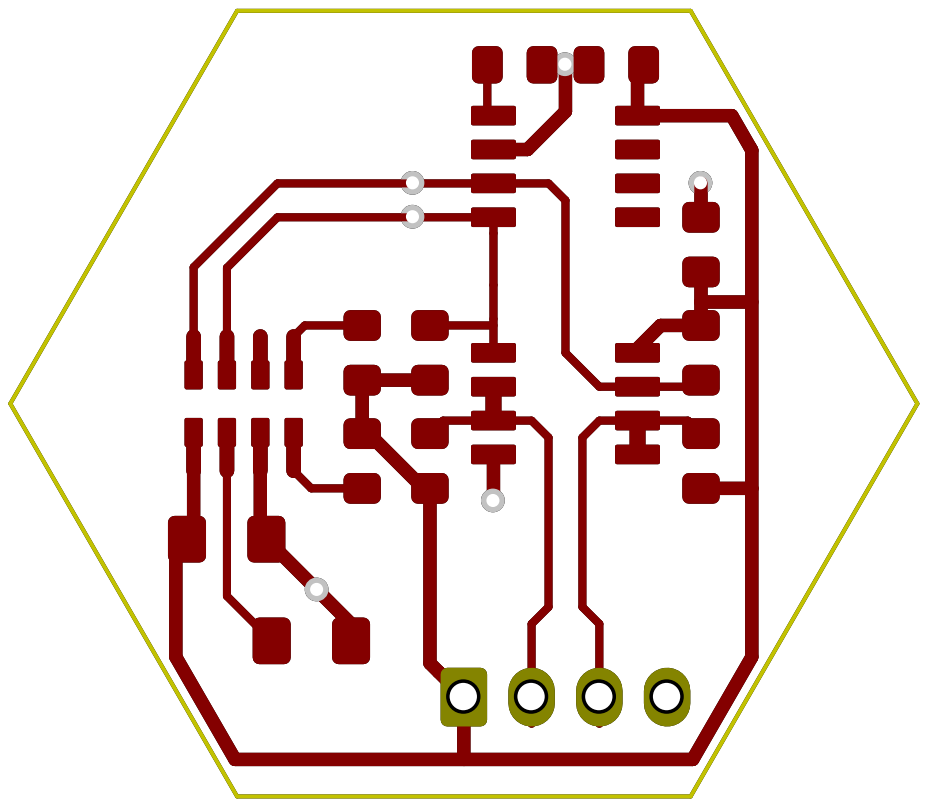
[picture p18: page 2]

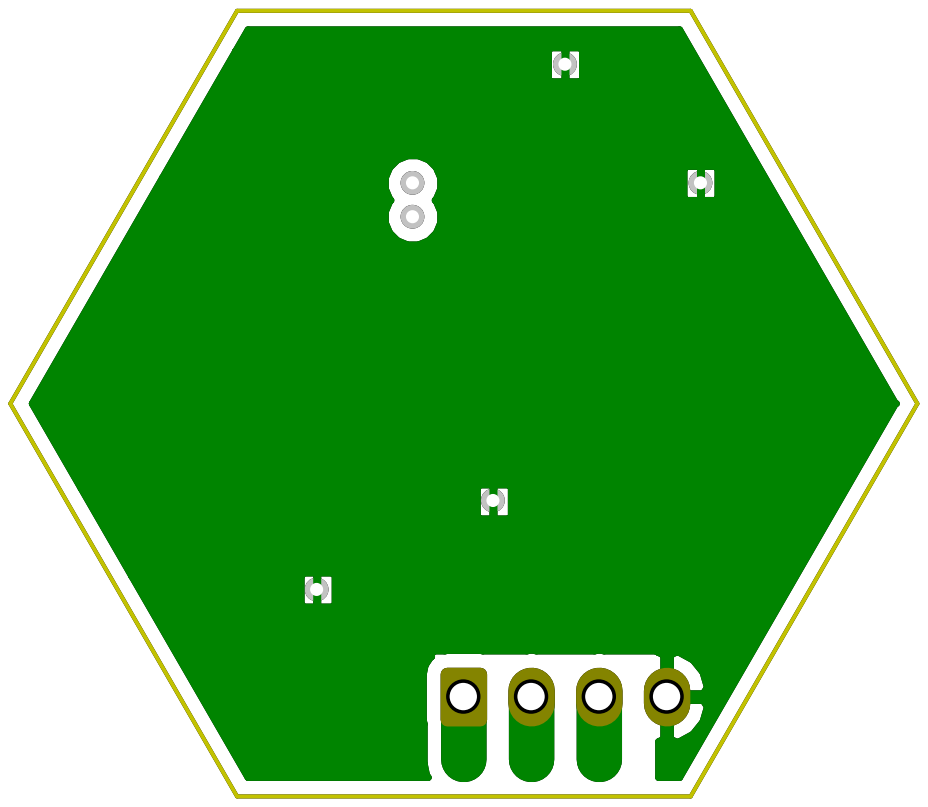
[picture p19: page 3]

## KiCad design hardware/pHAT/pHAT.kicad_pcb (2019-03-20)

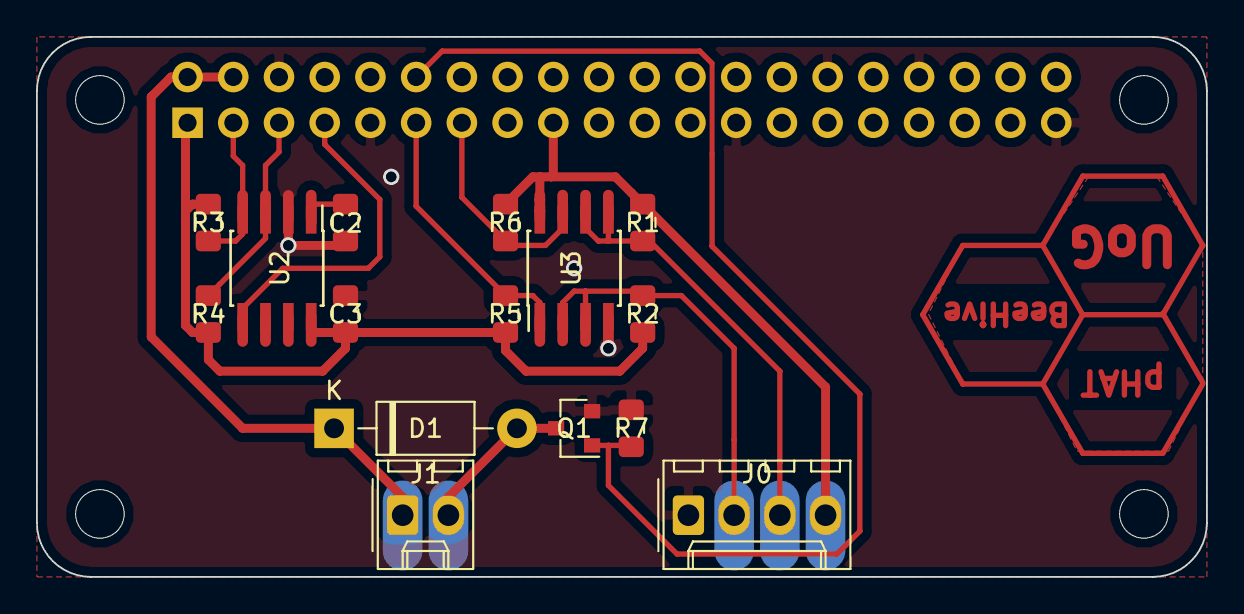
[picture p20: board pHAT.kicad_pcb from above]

Board: 2 copper layers, 65.0 x 30.0 mm, 20 parts (1 on the bottom side), 13 nets.

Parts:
C2: 0.1µ; C_0805_2012Metric_Pad1.15x1.40mm_HandSolder
C3: 0.22µ; C_0805_2012Metric_Pad1.15x1.40mm_HandSolder
D1: 1N4007; D_DO-41_SOD81_P10.16mm_Horizontal
J0: Conn_01x04; Molex_KK-254_AE-6410-04A_1x04_P2.54mm_Vertical
J1: Conn_01x02; Molex_KK-254_AE-6410-02A_1x02_P2.54mm_Vertical
MK1, MK2, MK3, MK4: M2.5; MountingHole_2.7mm_M2.5
P1: Conn_02x20_Odd_Even; PinSocket_2x20_P2.54mm_Vertical
Q1: 2N7002; SOT-23
R1, R2, R3, R4, R5, R6, R7: 5K; R_0805_2012Metric_Pad1.15x1.40mm_HandSolder
U2: HIH6131-021; SOIC-8_3.9x4.9mm_P1.27mm
U3: P82B96; SOIC-8_3.9x4.9mm_P1.27mm

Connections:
+3V3: C3.1, J0.4, P1.1, P1.17, R1.1, R2.1, R3.1, R4.1, R5.1, R6.1, U2.8, U3.8
+5V: D1.1, J1.1, P1.2, P1.4
/SCL0: P1.5, R4.2, U2.3
/SCL1: P1.13, R6.2, U3.7
/SCLA: J0.3, R1.2, U3.5, U3.6
/SDA0: P1.3, R3.2, U2.4
/SDA1: P1.11, R5.2, U3.1
/SDAA: J0.2, R2.2, U3.2, U3.3
/Vcore: C2.1, U2.1
/alarm_hive: P1.7, U2.5
/cmd: P1.12, Q1.1, R7.1
/fan_cmd: D1.2, J1.2, Q1.3
GND: C2.2, C3.2, J0.1, P1.6, P1.9, P1.14, P1.20, P1.25, P1.30, P1.34, P1.39, Q1.2, R7.2, U2.2, U3.4

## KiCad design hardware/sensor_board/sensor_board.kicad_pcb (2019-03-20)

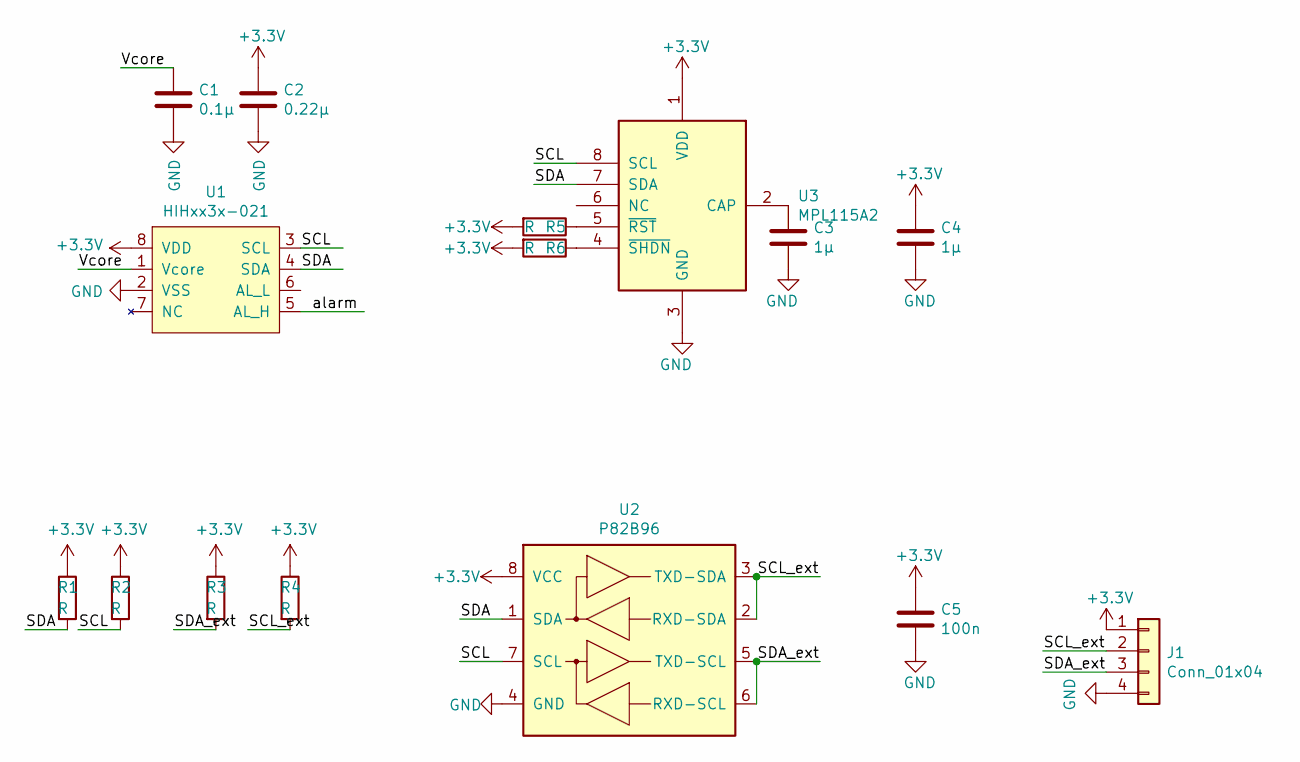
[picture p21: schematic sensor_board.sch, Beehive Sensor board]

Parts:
C1: 0.1µ; C_0805_2012Metric_Pad1.15x1.40mm_HandSolder
C2: 0.22µ; C_0805_2012Metric_Pad1.15x1.40mm_HandSolder
C3, C4: 1µ; C_1206_3216Metric_Pad1.42x1.75mm_HandSolder
C5: 100n; C_0805_2012Metric_Pad1.15x1.40mm_HandSolder
J1: Conn_01x04; Molex_KK-254_AE-6410-04A_1x04_P2.54mm_Vertical
R1, R2, R3, R4, R5, R6: R; R_0805_2012Metric_Pad1.15x1.40mm_HandSolder
U1: HIHxx3x-021; SOIC-8_3.9x4.9mm_P1.27mm
U2: P82B96; SOIC-8_3.9x4.9mm_P1.27mm
U3: MPL115A2; LGA-8_3x5mm_P1.25mm

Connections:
+3V3: C2.1, C4.1, C5.1, J1.1, R1.1, R2.1, R3.1, R4.1, R5.2, R6.2, U1.8 (VDD), U2.8 (VCC), U3.1 (VDD)
/SCL: R2.2, U1.3 (SCL), U2.7 (SCL), U3.8 (SCL)
/SCL_ext: J1.2, R4.2, U2.2 (RXD-SDA), U2.3 (TXD-SDA)
/SDA: R1.2, U1.4 (SDA), U2.1 (SDA), U3.7 (SDA)
/SDA_ext: J1.3, R3.2, U2.5 (TXD-SCL), U2.6 (RXD-SCL)
/Vcore: C1.1, U1.1 (Vcore)
/alarm: U1.5 (AL_H)
GND: C1.2, C2.2, C3.2, C4.2, C5.2, J1.4, U1.2 (VSS), U2.4 (GND), U3.3 (GND)
unnamed: C3.1, U3.2 (CAP)
unnamed: R5.1, U3.5 (~RST)
unnamed: R6.1, U3.4 (~SHDN)

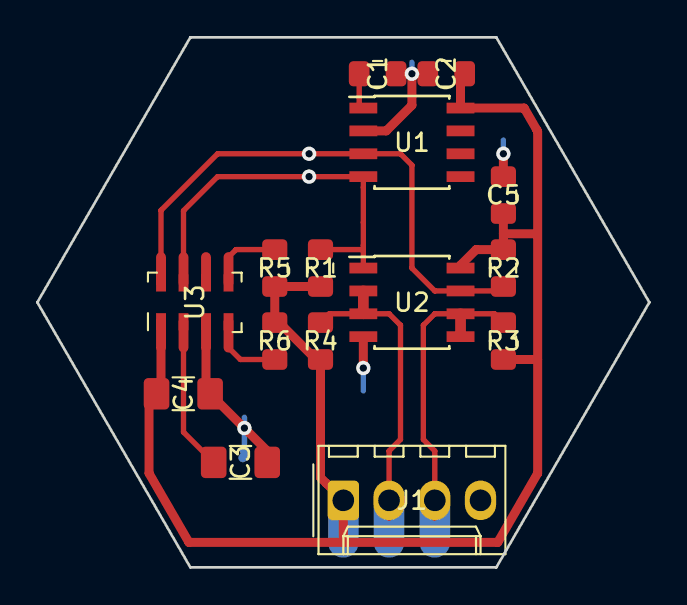
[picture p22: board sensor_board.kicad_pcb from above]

Board: 2 copper layers, 34.0 x 29.4 mm, 15 parts (0 on the bottom side), 10 nets.

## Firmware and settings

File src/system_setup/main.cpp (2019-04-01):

/**
 * Configure the Honeywell HumidIcon™ Digital Humidity/Temperature Sensors,
 * trigger the alarm high on 80% humidity and off on 75% humidity
 */

#include "I2C.hpp"
#include <iostream>
#include <stdio.h>
#include <stdlib.h>

#define I2C_PORT (char*)"/dev/i2c-1"
#define ADDR_TEMP_AND_HUM 0X27
unsigned char global_buffer[4]={0};


int main(int argc, const char* argv[] ){

  global_buffer[2] = 0x00;
  global_buffer[1] = 0x00;
  global_buffer[0] = 0xA0;

  I2C* bus = new I2C(I2C_PORT, ADDR_TEMP_AND_HUM);
  while(  bus->writeI2C(3, global_buffer) != 1);
  sleep(1);

	global_buffer[2]= 0x00;
	global_buffer[1]= 0x00;
	global_buffer[0]= 0x18;
	bus->writeI2C(3, global_buffer);

  bus->readI2C(3, global_buffer);
  std::cout <<(int) global_buffer[0] << std::endl;
  std::cout << (int)global_buffer[1] <<std::endl;
  std::cout << (int)global_buffer[2] << std::endl;

  /*! \brief Set Set Alarm_High_On = 80% Humidity.
  *         (Write 0x3333 to EEPROM Location 0x18).
  */
  global_buffer[0] = 0x58;
  global_buffer[1] = 0x26;
  global_buffer[2] = 0x65;
  bus->writeI2C(3, global_buffer);

  /*! \brief Set Set Alarm_High_Off = 75% Humidity.
  *         (Write 0x3000 to EEPROM Location 0x19).
  */
  global_buffer[0] = 0x59;
  global_buffer[1] = 0x1F;
  global_buffer[2] = 0xFF;
  bus->writeI2C(3, global_buffer);

}

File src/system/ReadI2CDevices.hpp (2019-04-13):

//! Class to gather all the readings form the diff sensors
/*!
   Hold all the addresses for the different sensors we want to read/write to.
   Gather the human readable values from the sensors,
   for easy use outside the class.
*/


#ifndef READI2CDEVICES_HPP
#define READI2CDEVICES_HPP

#include "TemperatureAndHumidity.hpp"
#include "Pressure.hpp"
#include "Sensor.hpp"
#include <string>

#define I2C_PORT1 (char*)"/dev/i2c-1"
#define I2C_PORT2 (char*)"/dev/i2c-3"

#define NB_DEVICES_PORT1 2
#define NB_DEVICES_PORT2 1
#define NB_DEVICES 3

#define PORT1_ADDR_TEMP_AND_HUM 0X27
#define PORT2_ADDR_PRESSURE 0X60
#define PORT2_ADDR_TEMP_AND_HUM 0X27



class ReadI2CDevices{

private:

  //! A private variable.
  /*!
    Global buffer where all the sensors saves the measurements.
  */
  unsigned char global_buffer[20]={0};
  //! A private variable.
  /*!
    Sensor object, pointing to the temperature and humidity sensor on I2C bus 1.
  */
  Sensor* th1;
  //! A private variable.
  /*!
    Sensor object, pointing to the temperature and humidity sensor on I2C bus 2.
  */
  Sensor* th2;
  //! A private variable.
  /*!
    Sensor object, pointing to the pressure sensor on I2C bus 1.
  */
  Sensor* pr;
  //std::vector<Sensor*> sensors;
  //Sensor* sensors[NB_DEVICES];

  //! Create all the sensor objects we want to communicate with
  /*!
    Called by the constructor.
    Saves the objects in the corresponding private variables.
    \sa ReadI2CDevices();
  */
  void createSensorObjects();

public:
    //! A constructor.
    /*!
      Call the function createSensorObjects();
      \sa createSensorObjects()
    */
    ReadI2CDevices();
    //! Write to all the peripherals.
    /*!
      Call the virtual function writeI2C() in Sensor.hpp for all the sensors
      \sa writeI2C()
    */
    void writeAll();
    //! Read data from all the peripherals.
    /*!
      Call the pure virtual function readI2C(unsigned char* global_buffer) in Sensor.hpp for all the sensors.
      Sends the private global_buffer to save the readings.
      \return A string of all the human readable data read form the sensors
      \sa readI2C(unsigned char* global_buffer)  = 0;
    */
    std::string readAll();
    //! A destructor.
    /*!
      Deallocates memory from heap
    */
    ~ReadI2CDevices();
};

#endif // READI2CDEVICES_HPP

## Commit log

2019-01-18 datasheet upload
    Uploading datasheets of the various components (ADC, I2C multiplexer, and sensors)
2019-01-21 pHAT base board
    Creation of the pHAT board
    [pHAT.kicad_pcb, pHAT.sch]
2019-01-21 First version of PCB for pHAT
    [pHAT.kicad_pcb, pHAT.sch]
2019-01-22 graphical improvements to PCB
    Added a logo and cleaned some tracks
    [pHAT.kicad_pcb]
2019-01-22 First version of sensor board
    Added a sensor board for the HIH61 humidity and temperature sensor
    [pHAT.kicad_pcb, sensor_board.kicad_pcb, sensor_board.sch]
2019-01-23 small changes to test on the raspberry
2019-01-23 Testing I2C on RPI
2019-01-23 Moving form multiplexer to two I2C busses
    Changed from using one I2C bus with a multiplexer to using two I2C busses with the addition of level shifters
    [pHAT.kicad_pcb, pHAT.sch, sensor_board.kicad_pcb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]
2019-01-26 Sensor board v2 and improvements to pHAT
    Added a I2C level shifter to the sensor board, which lead to a complete redesign
    Some graphical improvements to the pHAT
    [pHAT.kicad_pcb, pHAT.sch, sensor_board.kicad_pcb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]
2019-01-29 Added the alarm pin for humidity
    Added support for the alarm pin of the HIH6131 in order to detect through interrupt a high level of humidity
    [pHAT.kicad_pcb, pHAT.sch, sensor_board.kicad_pcb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]
2019-01-30 Adding smd pad for connectors
    Adding SMD pads to allow surface soldering at right angle of Molex JYK connectors
    [pHAT.kicad_pcb]
2019-01-30 added smalle changes to read the i2c buffer
2019-02-02 add small changes to the I2C and TemperaturAndHumidity
2019-02-02 change the I2C template, add template ADC
2019-02-06 print sentence
2019-02-06 add print sentence
2019-02-06 add print
2019-02-06 test reading from sensor
2019-02-06 hanging the printing in I2c
2019-02-06 added integer I2c
2019-02-06 print bits
2019-02-11 printing out bit
2019-02-11 printing the bitsets again
2019-02-11 Add new class for thread: reading all devices
2019-02-12 Start of hardware redesign
    [sensor_board.kicad_pcb]
2019-02-12 Sensor Board v3.0
    Removed ADC converter, moved the hive temp&hum sensor to the main board that will now be placed inside the hive
    [pHAT.kicad_pcb, pHAT.sch]
2019-02-17 Preparing layout for adding a fan
    [pHAT.kicad_pcb, pHAT.sch, sensor_board.kicad_pcb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]
2019-02-18 test if i2c-3 is open
2019-02-18 add thread to read sensors
2019-02-18 Finished fan command circuit (pHAT v3.2)
    [pHAT.kicad_pcb, pHAT.sch]
2019-02-18 add abstract sensor class
2019-02-18 add abstract sensor class, actually including the sensor.hpp file
2019-02-20 sockets not completed
2019-02-27 sockets working
2019-03-12 add class Fan
2019-03-12 add testing code fan
2019-03-12 Rework of sensor board and correction of pHAT
    [pHAT.kicad_pcb, pHAT.sch, sensor_board.kicad_pcb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]
2019-03-12 Fan and timer is working on RaspberryPi
2019-03-12 Timer starts thread to read sensors, working
2019-03-12 add class Pressure Sensor
2019-03-12 add include pressure in ReadAllDevices
2019-03-13 add I2C addr for pressure sensor
2019-03-13 add code for reading all the sensors
2019-03-13 fix bug writing sensors
    [ReadI2CDevices.cpp]
2019-03-13 fixing caps look code..
    [ReadI2CDevices.cpp]
2019-03-13 fixing caps look code2..
    [ReadI2CDevices.cpp]
2019-03-13 reading and printing the temp bits
2019-03-13 printing the actual bits
2019-03-14 fix bug ReadI2CDevices in constructor
    [ReadI2CDevices.cpp]
2019-03-15 CHanging the formula Pressure sensor
2019-03-15 adding pressure comp
2019-03-18 adding udp connection and fixing clinet sockets
2019-03-19 add pressure coefficients in pressure class
2019-03-20 Polishing the board
    [pHAT.kicad_pcb, pHAT.sch, sensor_board.kicad_pcb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]
2019-03-20 sending correct data to server
    [ReadI2CDevices.cpp, ReadI2CDevices.hpp]
2019-03-20 the client is done, sending the correct data, yeah
    [ReadI2CDevices.cpp]
2019-03-23 add function to receive interrupts on spesifiec pin
2019-03-23 add pressure coefficients, trying to read
2019-03-25 comment outdouble declaration of fan in main
2019-03-25 makie static helper function for thread
2019-03-25 correct interrupt code
2019-03-25 testing more general interrupt code in Fan
2019-03-25 remove print sentences and send pressure data to server
2019-03-25 adding pressure
2019-03-25 add system_setup fro programming the humid sensor
2019-03-25 Adding boards datasheets
2019-03-25 add print sentence alarm pin
2019-03-25 writing correct to temp&hum sensor- alarm should be configured correct
    [main.cpp]
2019-03-25 stupid wiringPi library doesnt work
2019-03-26 add print-sentence to debug
2019-03-26 add static pointer to the fan
2019-03-26 done everything in software to make wiringPi work. Only read high on gpio 7
2019-03-26 testing hard-coding fan
2019-03-26 fan is workinggit status git status eveerything is working - HAPPY TRINE
2019-04-13 doxygen comments I2C
2019-04-13 doxygen comments Temperatur&humidity
2019-04-13 doxygen comments Pressure
2019-04-13 doxygen comments Sensor
2019-04-13 doxygen comments Fan
2019-04-13 doxygen comments TimerEvent, delete Cpptimer.cpp and made a new class instead
2019-04-14 removed wiringpi lib in the cmakefile in the setup
